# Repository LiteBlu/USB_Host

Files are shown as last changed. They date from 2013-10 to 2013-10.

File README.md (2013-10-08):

#Introduction

The LiteBlu USB Host is a Microchip PIC microcontroller board which contains a built-in full-speed USB host controller. This allows the board to connect to and control any USB device.

#Features
	No USB Programming required
	UART and I2C interface
	Software upgradable via UART using built in bootloader (DS30Loader)
	Available firmware
	USB Flash Drive
	USB Keyboard (coming soon)
	USB Mouse (coming soon)
	USB Joystick (coming soon)
	Built-in Real Time Clock
	5V and 3.3V compatible
	On-board 3.3V regulator with output (up to 250mA)

#Host software
##Flash Drive

The Flash Drive Host Software allows you to read/write from/to a USB Flash Drive. You can connect to it using terminal software (RS232 to serial TTL convertion required) or directly to your 5V or 3.3V microcontroller.

###Features
	Supports FAT16 and FAT32 formats
	Simple serial (UART) interface
	Silent mode or terminal mode

###Required Connections
	5V Power [INPUT]
	GND
	TX [OUTPUT]
	RX [INPUT]
	SS [OUTPUT] Optional. Goes high when USB Flash Drive connected, low if removed.

###Supported Commands

#Programming
This section describes how to reprogram the LiteBlu USB Host using the built in bootloader.

The built in bootloader is the free DS30Loader.
DS30Loader Setup
Browse to the downloaded hex file
Select the correct device. PIC24FJ 64GB0002
Select the Baud rate as 115200
Select the correct serial port that the USB Host is connected to
Tick "Write Flash"
Select "Xon/Xoff" Flow Control

Then put the USB Host into bootloader mode by resetting it. This can be done by toggling the power, or by shorting the reset pin to ground. The reset pin is the square pad on the 5-way (ICSP) connector on the side of the USB Host board and GND is the center pin on the 5-way (ICSP) connector. The green LED will light up for the entire duration (3 seconds) the USB Host board is in the bootloader.

After resetting the USB Host board, immediately(within 3 seconds) click "Write" in the top left corner of the DS30Loader GUI.

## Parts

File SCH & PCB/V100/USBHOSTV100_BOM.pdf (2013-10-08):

## Bill of Materials For Schematic Document [USBHOSTV100.SchDoc]

0

Source Data From: | | USBHOSTV100.SchDoc
Project: | | USBHOSTV100.PrjPCB
Variant: | | None
Report Date: | 10/8/2013 | 7:43:26 PM
Print Date: | 08-Oct-13 | 7:43:28 PM

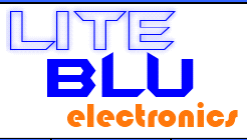
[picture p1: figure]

# | Designator | LibRef | Comment | Description | Footprint | Supplier | SupCode | Quantity

1 | C1 | Capacitor Ceramic | 10u | Capacitor Ceramic | CAP 0603 | | | 1
2 | C2 | Capacitor Ceramic | 100n | Capacitor Ceramic | CAP 0603 | | | 1
3 | C3 | Capacitor Ceramic | 10u | Capacitor Ceramic | CAP 0805 | | | 1
4 | C4, C5 | Capacitor Ceramic | 27p | Capacitor Ceramic | CAP 0603 | | | 2
5 | D1 | Diode | BAT54 | Default Diode | SOT-23 | | | 1
6 | D2, D3, D4 | LED | Value | LED | LED 0603 | | | 3
7 | P2 | CONN - 9W | CONN - 9W | CONN - 9W | Header Female 09 2.54 | | | 1
8 | P3 | USB - TYPE-A | USB - TYPE-A | USB TYPE-A | USB - TYPE-A TH | | | 1
9 | R1, R2 | Resistor | 10k | Resistor | RES 0603 | | | 2
10 | R3, R4 | Resistor | 470R | Resistor | RES 0603 | | | 2
11 | R5 | Resistor | 220R | Resistor | RES 0603 | | | 1
12 | U1 | Regulator Adj 5pin | MCP1x0x | MIC5235 Adjustable Voltage Regulator, Low Quiesciet current, 150mA | SOT23-5 | | | 1
13 | U2 | PIC24FJ64GB002 | PIC24FJ64GB002 | | SOIC-28 | | | 1
14 | U3 | 24LC01 | 24LC01 | 1K I2C Serial EEPROM | SOT23-5 | | | 1
15 | X1 | Crystal | 8MHz | | Crystal SMU4 | | | 1
Approved | | | Notes | | | | | 20

# Bill Of Materials

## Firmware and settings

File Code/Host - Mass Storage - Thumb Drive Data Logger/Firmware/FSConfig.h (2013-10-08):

/******************************************************************************
 *
 *                Microchip Memory Disk Drive File System
 *
 ******************************************************************************
 * FileName:        FSconfig.h
 * Processor:       PIC18/PIC24/dsPIC30/dsPIC33/PIC32
 * Dependencies:    None
 * Compiler:        C18/C30/C32
 * Company:         Microchip Technology, Inc.
 * Version:         1.2.0
 *
 * Software License Agreement
 *
 * The software supplied herewith by Microchip Technology Incorporated
 * (the “Company”) for its PICmicro® Microcontroller is intended and
 * supplied to you, the Company’s customer, for use solely and
 * exclusively on Microchip PICmicro Microcontroller products. The
 * software is owned by the Company and/or its supplier, and is
 * protected under applicable copyright laws. All rights are reserved.
 * Any use in violation of the foregoing restrictions may subject the
 * user to criminal sanctions under applicable laws, as well as to
 * civil liability for the breach of the terms and conditions of this
 * license.
 *
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
*****************************************************************************/


#ifndef _FS_DEF_

#include "Compiler.h"
#include "HardwareProfile.h"


// Summary: A macro indicating the maximum number of concurrently open files
// Description: The FS_MAX_FILES_OPEN #define is only applicable when dynamic memory allocation is not used (FS_DYNAMIC_MEM is not defined).
//              This macro defines the maximum number of open files at any given time.  The amount of RAM used by FSFILE objects will
//              be equal to the size of an FSFILE object multipled by this macro value.  This value should be kept as small as possible
//              as dictated by the application.  This will reduce memory usage.
#define FS_MAX_FILES_OPEN 	2


// Summary: A macro defining the size of a sector
// Description: The MEDIA_SECTOR_SIZE macro will define the size of a sector on the FAT file system.  This value must equal 512 bytes,
//              1024 bytes, 2048 bytes, or 4096 bytes.  The value of a sector will usually be 512 bytes.
#define MEDIA_SECTOR_SIZE 		512

//#define SUPPORT_LFN

/* *******************************************************************************************************/
/************** Compiler options to enable/Disable Features based on user's application ******************/
/* *******************************************************************************************************/


// Summary: A macro to enable/disable file search functions.
// Description: The ALLOW_FILESEARCH definition can be commented out to disable file search functions in the library.  This will
//              prevent the use of the FindFirst and FindNext functions and reduce code size.
#define ALLOW_FILESEARCH

// Summary: A macro to enable/disable write functionality
// Description: The ALLOW_WRITES definition can be commented out to disable all operations that write to the device.  This will
//              greatly reduce code size.
#define ALLOW_WRITES


// Summary: A macro to enable/disable format functionality
// Description: The ALLOW_FORMATS definition can be commented out to disable formatting functionality.  This will prevent the use of
//              the FSformat function.  If formats are enabled, write operations must also be enabled by uncommenting ALLOW_WRITES.
//#define ALLOW_FORMATS

// Summary: A macro to enable/disable directory operations.
// Description: The ALLOW_DIRS definition can be commented out to disable all directory functionality.  This will reduce code size.
//              If directories are enabled, write operations must also be enabled by uncommenting ALLOW_WRITES in order to use
//              the FSmkdir or FSrmdir functions.
#define ALLOW_DIRS

// Summary: A macro to enable/disable PIC18 ROM functions.
// Description: The ALLOW_PGMFUNCTIONS definition can be commented out to disable all PIC18 functions that allow the user to pass string
//              arguments in ROM (denoted by the suffix -pgm).  Note that this functionality must be disabled when not using PIC18.
//#define ALLOW_PGMFUNCTIONS

// Summary: A macro to enable/disable the FSfprintf function.
// Description: The ALLOW_FSFPRINTF definition can be commented out to disable the FSfprintf function.  This will save code space.  Note that
//              if FSfprintf is enabled and the PIC18 architecture is used, integer promotions must be enabled in the Project->Build Options
//              menu.  Write operations must be enabled to use FSfprintf.
//#define ALLOW_FSFPRINTF

// Summary: A macro to enable/disable FAT32 support.
// Description: The SUPPORT_FAT32 definition can be commented out to disable support for FAT32 functionality.  This will save a small amount
//              of code space.
#define SUPPORT_FAT32
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

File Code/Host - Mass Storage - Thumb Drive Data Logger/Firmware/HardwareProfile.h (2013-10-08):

// HardwareProfile.h

#ifndef _HARDWARE_PROFILE_H_
#define _HARDWARE_PROFILE_H_

// Define your clock speed here

// Sample clock speed for a 16-bit processor
#if defined (__C30__)

    // Various clock values
    #define GetSystemClock()            32000000UL
    #define GetPeripheralClock()        (GetSystemClock())
    #define GetInstructionClock()       (GetSystemClock() / 2)

    // Clock values
    #define MILLISECONDS_PER_TICK       10
    #define TIMER_PRESCALER             TIMER_PRESCALER_8   // 8MHz: TIMER_PRESCALER_1
    #define TIMER_PERIOD                20000                // 10ms=20000, 1ms=2000

#elif defined( __PIC32MX__)

    #define USB_A0_SILICON_WORK_AROUND
    //#define RUN_AT_48MHZ
    //#define RUN_AT_24MHZ
    #define RUN_AT_60MHZ
    
    // Various clock values
    #if defined(RUN_AT_48MHZ)
        #define GetSystemClock()            48000000UL
        #define GetPeripheralClock()        48000000UL
        #define GetInstructionClock()       (GetSystemClock() / 2) ???
    #elif defined(RUN_AT_24MHZ)
        #define GetSystemClock()            24000000UL
        #define GetPeripheralClock()        24000000UL
        #define GetInstructionClock()       (GetSystemClock() / 2) ???
    #elif defined(RUN_AT_60MHZ)    
        #define GetSystemClock()            60000000UL
        #define GetPeripheralClock()        60000000UL  // Will be divided down
        #define GetInstructionClock()       (GetSystemClock() / 2) ???
    #else
        #error Choose a speed
    #endif    

    // Clock values
    #define MILLISECONDS_PER_TICK       10                  // -0.000% error
    #define TIMER_PRESCALER             TIMER_PRESCALER_8   // At 60MHz
    #define TIMER_PERIOD                37500               // At 60MHz

#endif


//#define USE_USB_PLL

#if defined(__PIC32MX__)
#endif


// Define the baud rate constants
#if defined(__C30__)
    #define BAUDRATE2       57600UL
    #define BAUDRATE2400    2400UL
    #define BAUDRATE4800    4800UL
    #define BAUDRATE9600    9600UL
    #define BAUDRATE14400   14400UL
    #define BAUDRATE19200   19200UL
    #define BAUDRATE28800   28800UL
    #define BAUDRATE38400   38400UL
    #define BAUDRATE57600   57600UL
    #define BAUDRATE115200  115200UL
    #define BRG_DIV2        4
    #define BRGH2           1

    #define BAUD2400        (((GetSystemClock()/2)+(BRG_DIV2/2*BAUDRATE2400))/BRG_DIV2/BAUDRATE2400-1)
    #define BAUD4800        (((GetSystemClock()/2)+(BRG_DIV2/2*BAUDRATE4800))/BRG_DIV2/BAUDRATE4800-1)
    #define BAUD9600        (((GetSystemClock()/2)+(BRG_DIV2/2*BAUDRATE9600))/BRG_DIV2/BAUDRATE9600-1)
    #define BAUD14400       (((GetSystemClock()/2)+(BRG_DIV2/2*BAUDRATE14400))/BRG_DIV2/BAUDRATE14400-1)
    #define BAUD19200       (((GetSystemClock()/2)+(BRG_DIV2/2*BAUDRATE19200))/BRG_DIV2/BAUDRATE19200-1)
    #define BAUD28800       (((GetSystemClock()/2)+(BRG_DIV2/2*BAUDRATE28800))/BRG_DIV2/BAUDRATE28800-1)
    #define BAUD38400       (((GetSystemClock()/2)+(BRG_DIV2/2*BAUDRATE38400))/BRG_DIV2/BAUDRATE38400-1)
    #define BAUD57600       (((GetSystemClock()/2)+(BRG_DIV2/2*BAUDRATE57600))/BRG_DIV2/BAUDRATE57600-1)
    #define BAUD115200      (((GetSystemClock()/2)+(BRG_DIV2/2*BAUDRATE115200))/BRG_DIV2/BAUDRATE115200-1)
#elif defined (__PIC32MX__)
    #define BAUDRATE2       57600UL
    #define BRG_DIV2        4 
    #define BRGH2           1 
#endif

#if defined(__PIC24F__)
    #include <p24Fxxxx.h>
    #include <uart2.h>
#elif defined(__PIC24H__)
    #include <p24hxxxx.h>
    #include <uart2.h>
#else
    #include <p32xxxx.h>
    #include <plib.h>
    #include <uart2.h>
#endif


// Select your MDD File System interface type
// This library currently only supports a single physical interface layer

//#define USE_SD_INTERFACE_WITH_SPI       // SD-SPI.c and .h
//#define USE_CF_INTERFACE_WITH_PMP       // CF-PMP.c and .h
//#define USE_MANUAL_CF_INTERFACE         // CF-Bit transaction.c and .h
#define USE_USB_INTERFACE               // USB host MSD library



/** TRIS ***********************************************************/
#define INPUT_PIN           1
#define OUTPUT_PIN          0

#endif  
